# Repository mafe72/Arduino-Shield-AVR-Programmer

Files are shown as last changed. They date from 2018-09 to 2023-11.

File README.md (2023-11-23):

# Arduino Shield AVR Programmer



The Arduino software comes with an ArduinoISP sketch which allows an Arduino, correctly connected, to flash another AVR chip. With the use of other libraries like Attiny-core, this means you can use your Arduino and it’s IDE to program Attiny chips! This shield takes all the hassle out of connecting the wires, and with the simple use of a jumper cable, lets you program 8, 14, 20, and 28-pin chips with one easy-to-use zero insertion force (ZIF) socket!

- Load a bootloader on an Atmega328 as a replacement or for a breadboard project.
- Load a program on an Attiny 84, 85, or 2313 using the Arduino IDE.
- Update a program on any AVR project that has an ISP header.

License
-------
<div align="center"><br /></div>

This project is open hardware licensed under the Attribution-ShareAlike 4.0 (CC BY-SA 4.0) license. The full legal text of the license may be found in the LICENSE.md file in this repository. For more information about this license, please visit 
the Creative Commons Foundation (https://creativecommons.org/licenses/by-sa/4.0/).

Features:
-------

- Reprogram a chip in an existing circuit with an ISP header.
- Simple and easy jumper system allows programming 8, 14, 20, and 28 pin chips using a single socket.
- LEDs give the status of the programmer.
- Support for a piezo beeper for error/success audible tones.
- An indicator light on pin D3 lets you run “BLINK” on any of the chips while it is in the socket.
- Compatible with ArduinoISP, AdafruitISP, and AdaLoader.
- Tested on Duemilanove, Uno, and Mega (requires jumpers).
- Use an IDC 6 Pin Ribbon Cable to connect the ISP port to the desired IC pinout.

----------
Front Side:
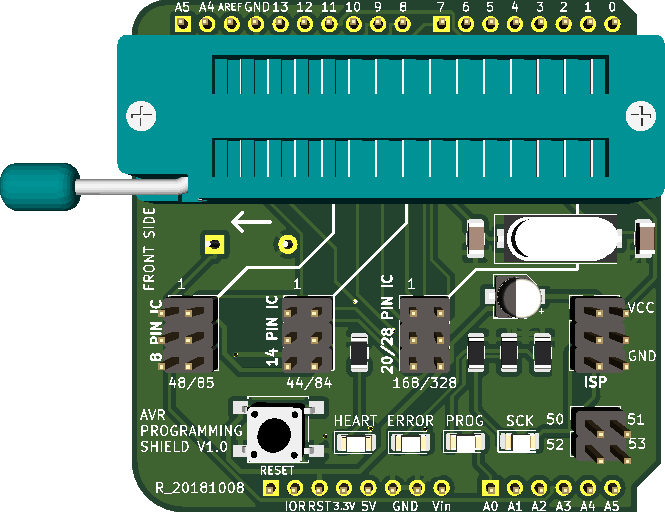
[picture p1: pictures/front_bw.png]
Arduino Shield AVR Programmer Front Side

----------
Back Side:
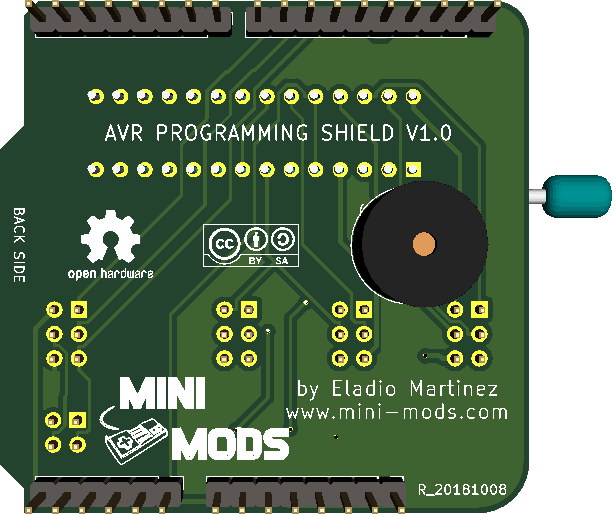
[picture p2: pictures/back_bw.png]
Arduino Shield AVR Programmer Back Side

----------

Project
-------

The PCB design was originally developed in Kicad.

# Contribution

## Suggestions and Bugs in Hardware

You should report bugs or suggestions via [Issues area](https://github.com/mafe72/Arduino-Shield-AVR-Programmer/issues) here in github.

Make sure you meet the following criteria when creating / submitting your issue:

- Use a clear and descriptive title to identify the problem / suggestion.
- Describe the exact steps to reproduce the problem in as much detail as possible.
- Mention where this problem was found / what your suggestion will affect.

## Contribution to hardware improvements

Community contributions are always welcome!

This section is intended to help anyone interested in contributing to this repository.
Before you contribute, first get approval from the repository and community maintainers by raising a problem from GitHub using the guidelines mentioned in the suggestions section.
 
Once you get approved, you will need to do the following steps (these instructions assume that you are a GitHub user).

- 1: fork this repository.
- 2: Make changes, commit and push to the fork.
- 3: Submit your Pull Request.

## If you have any questions please contact me

info@attinyuino.com

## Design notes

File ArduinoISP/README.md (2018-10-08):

Arduino Shield AVR Programmer Sketch
----------------

This sketch turns the Arduino into a AVRISP and takes advantage of the Piezo Speaker on pin A3 to provide audible tones.

If you want to program anything other than the standard bootloaders, you will need to add the appropriate "cores" to the Arduino software:

* For a "Breadboard Arduino", which is an Atmega328 running on its internal crystal at 8 MHz, you must install the files from "Breadboard.zip" at http://arduino.cc/en/Tutorial/ArduinoToBreadboard into the "hardware" folder in your Arduino "sketchbook" folder.
* For Attiny chips, there are several cores available:
	* I like [Arduino-Tiny](https://code.google.com/archive/p/arduino-tiny/) core based on work by David A. Mellis, René Bohne, R. Wiersma, Alessandro Saporetti, and Brian Cook because it supports the tone() command if you want to play sounds on a piezo speaker.
	* If you want to program the Attiny2313, you can use the [Attiny](https://github.com/damellis/attiny/) core.

Leds & buzzer:
----------------

- Green LED : HEART - (Heartbeat) shows the programmer is running.
- Red LED : ERROR - Lights up if something goes wrong and the the piezo makes a continuous beep.
- Yellow LED: PROG - (Programming) In communication with the slave, once it is done, the piezo makes a short beep.
- Blue LED: SCK  - (Activity) active when data is transmitted.

Arduino Mega:
----------------

This shield will work with the mega, but needs a 2x2 female header added in the lower right corner and four jumper wires to connect with Mega pins 50 - 53.

Settings:
----------------

1. Upload the ArduinoISP.ino provided on this section. This sketch must be uploaded without the shield in place since the shield has a capacitor to over-ride the reset signal (or you could use a manual reset before upload, like in the old-old days). Alternatively you can use the stock Arduino software "ArduinoISP" sketch included in the "Examples" section. 
2. With the sketch uploaded, install the shield. You should see the green heart LED begin it's pulsing.
3. In the IDE, select "Tools" -> "Programmer" -> "Arduino as ISP".
4. Select the target chip type using "Tools" -> "Boards".
5. Place an IDC 6 Pin (2x3) X 2 Ribbon Cable (jumper cable can also be used) between the "ISP" header and the correct header for the chip type.

Burning:
----------------

Setting fuses is a scary and confusing topic if you look in to it much. Don't bother. They are basically setting that tell the chip how to behave and have to be done only once to a new chip.

1. Place the chip in the ZIFF socket, all the way to the left, with Pin 1 in the lower-left corner.
2. With the correct "board" selected for the target chip, select "Tools" -> "Burn Bootloader".
	* For an Atmega chip going in to a UNO or breadboard, this will set the fuses and upload the correct bootloader.
	* For an Attiny, this just sets the fuses. For us, this primarily concerns chip speed. 

Upload a Sketch:
----------------

1. Load the sketch for the target chip. Start with the basic blink "File" -> "Examples" -> "01.Basics" -> "Blink".
2. Change the "led" variable from "13" to "3".
3. Click the upload icon, or "File" -> "Upload".
4. You should see the yellow LED flash and get an "Upload Complete" message.
5. If all is well, the target chip should start blinking the yellow LED (attached to D3).

Troubleshooting:
----------------

If you experience any problems double check the following:

1. "Tools" -> "Serial Port" -> Correct port selected. 
2. ArduinoISP sketch uploaded and green heartbeat beating.
	* Sometimes the sketch will hang and need a reset. 
3. "Tools" -> "Programmer" -> "Arduino as ISP".
4. "Tools" -> "Boards" -> target chip selected.
5. Jumper cable set to correct target chip type.
6. Target chip in the correct position with pin 1 to the lower left.

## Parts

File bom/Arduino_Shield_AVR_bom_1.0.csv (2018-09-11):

Component | Description | References | Value | Quantity Per PCB | MPN | Datasheet
1 | Buzzers Indicator, Internally Driven Magnetic 5V 40mA 2.3kHz 85dB @ 5V, 10cm Through Hole PC Pins | BZ1 | Buzzer | 1 | WST-1205S | http://cirlw3yrzg4afc1x47lv2k18.wpengine.netdna-cdn.com/wp-content/uploads/2016/12/WST-1205S-new.pdf
2 | 10µF 16V Aluminum Electrolytic Capacitors Radial, Can - SMD 2000 Hrs @ 85°C | C3 | 10uf | 1 | EEE-1CA100SR | https://industrial.panasonic.com/cdbs/www-data/pdf/RDE0000/ABA0000C1145.pdf
3 | 22pF ±5% 100V Ceramic Capacitor C0G, NP0 1206 (3216 Metric) | C1 C2 | 22pf | 2 | AC1206JRNPO0BN220 | http://www.yageo.com/documents/recent/UPY-AC_NP0X7R_16V-to-630V_11.pdf
4 | Red 638nm LED Indication - Discrete 1.8V 1206 (3216 Metric) | D3 | LED_ERR | 1 | LTST-C150CKT | http://optoelectronics.liteon.com/upload/download/DS-22-98-0002/LTST-C150CKT.pdf
5 | Green 569nm LED Indication - Discrete 2.1V 1206 (3216 Metric) | D4 | LED_HTE | 1 | LTST-C150GKT | http://optoelectronics.liteon.com/upload/download/DS-22-98-0004/LTST-C150GKT.pdf
6 | Yellow 591nm LED Indication - Discrete 2.1V 1206 (3216 Metric) | D2 | LED_PROG | 1 | LTST-C150KSKT | http://optoelectronics.liteon.com/upload/download/DS-22-99-0187/LTST-C150KSKT.pdf
7 | Blue 470nm LED Indication - Discrete 3.3V 1206 (3216 Metric) | D1 | LED_SCK | 1 | LTST-C150TBKT | http://optoelectronics.liteon.com/upload/download/DS22-2000-026/LTST-C150TBKT(0630).pdf
8 | CONN IC DIP SOCKET ZIF 24POS GLD | J5 | 28-PIN ZIF SOCKET | 1 | 224-5248-00-0602J | http://aitendo3.sakura.ne.jp/aitendo_data/product_img/parts/socket/LCC/3M-TEXTOOL-LCCC.PDF
9 | Connector Header Through Hole 6 position 0.100" (2.54mm) | J4 | ISP_329 | 1 | M20-9720345 | https://cdn.harwin.com/pdfs/M20-972.pdf
10 | Connector Header Through Hole 6 position 0.100" (2.54mm) | J3 | ISP_84 | 1 | M20-9720345 | https://cdn.harwin.com/pdfs/M20-972.pdf
11 | Connector Header Through Hole 6 position 0.100" (2.54mm) | J2 | ISP_85 | 1 | M20-9720345 | https://cdn.harwin.com/pdfs/M20-972.pdf
12 | Connector Header Through Hole 6 position 0.100" (2.54mm) | J1 | ISP_MASTER | 1 | M20-9720345 | https://cdn.harwin.com/pdfs/M20-972.pdf
13 | Connector Header Through Hole 4 position 0.100" (2.54mm) | J6 | MEGA_JUMPERS | 1 | 61300421121 | https://katalog.we-online.de/em/datasheet/6130xx21121.pdf
14 | Connector Header Through Hole 6 position 0.100" (2.54mm) | P2 | Analog | 1 | 61300611121 | https://katalog.we-online.de/em/datasheet/6130xx11121.pdf
15 | Connector Header Through Hole 10 position 0.100" (2.54mm) | P3 | Digital | 1 | 61301011121 | https://katalog.we-online.de/em/datasheet/6130xx11121.pdf
16 | Connector Header Through Hole 8 position 0.100" (2.54mm) | P4 | Digital | 1 | 61300811121 | https://katalog.we-online.de/em/datasheet/6130xx11121.pdf
17 | Connector Header Through Hole 8 position 0.100" (2.54mm) | P1 | Power | 1 | 61300811121 | https://katalog.we-online.de/em/datasheet/6130xx11121.pdf
18 | 330 Ohms ±1% 0.25W, 1/4W Chip Resistor 1206 (3216 Metric) Moisture Resistant Thick Film | R1 R2 R3 R4 | 330R | 4 | RC1206FR-07330RL | http://www.yageo.com/documents/recent/PYu-RC_Group_51_RoHS_L_9.pdf
19 | Tactile Switch SPST-NO Top Actuated Surface Mount | SW1 | SW_Push | 1 | TL3301AF260QG | http://spec_sheets.e-switch.com/specs/P010513.pdf
20 | 16MHz ±30ppm Crystal 18pF 30 Ohms HC-49/US | Y1 | 16MHz | 1 | 9C-16.000MAAJ-T | http://www.txccorp.com/download/products/quartz_crystals/2015TXC_9C_32.pdf

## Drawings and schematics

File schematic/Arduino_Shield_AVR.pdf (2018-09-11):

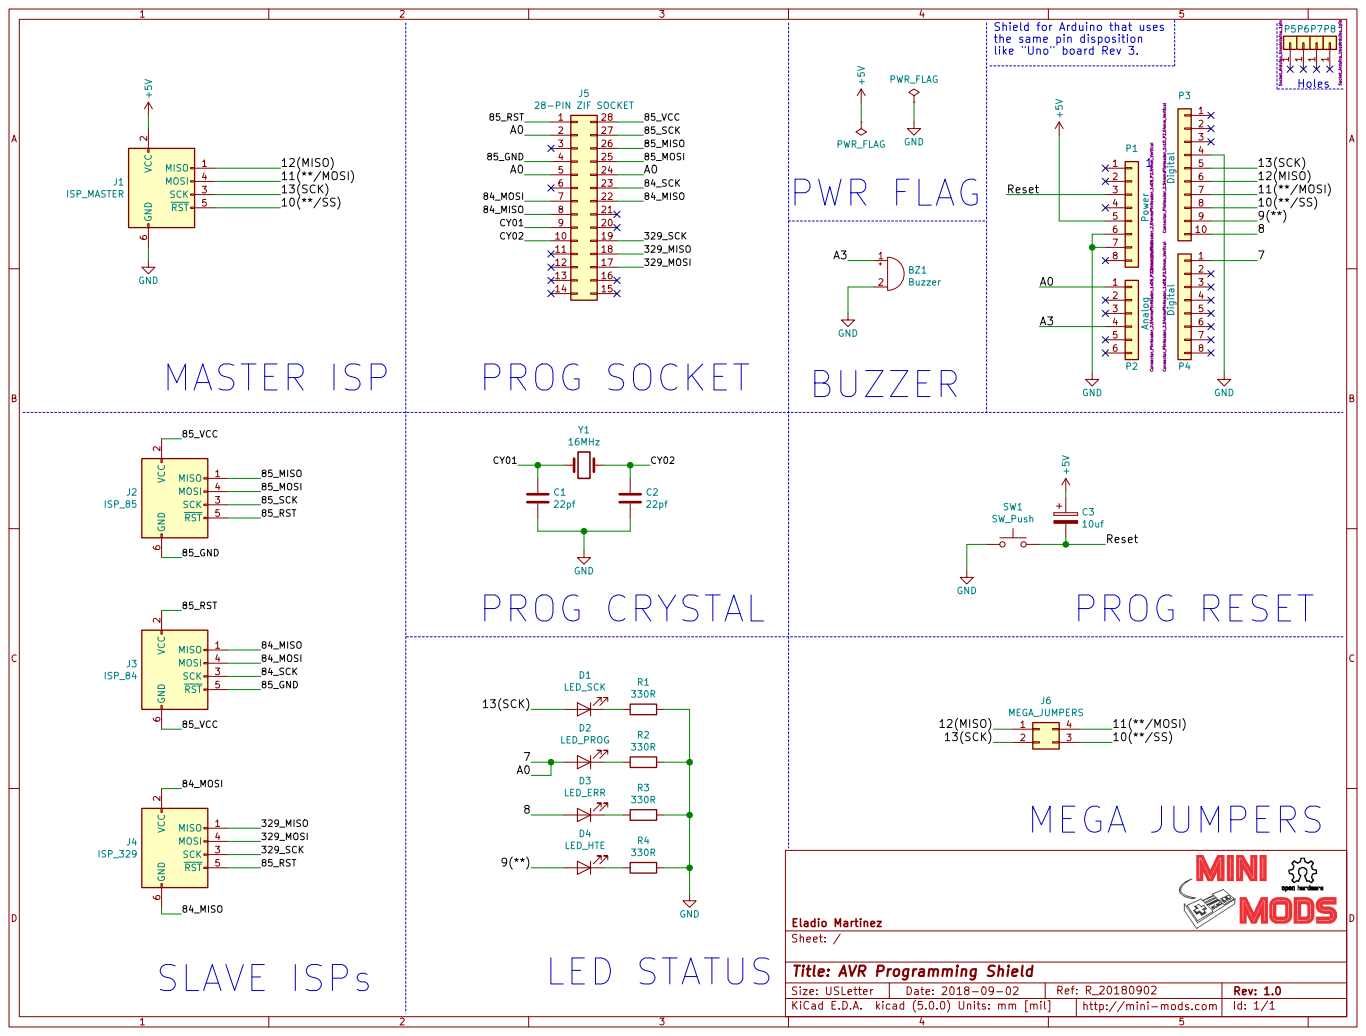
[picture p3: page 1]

13(SCK)Holes Shield for Arduino that uses
the same pin disposition
like "Uno" board Rev 3. 1

2 SCK 3 MOSI 4 RST 5 GND

Id: 1/1 Title: AVR Programming Shield

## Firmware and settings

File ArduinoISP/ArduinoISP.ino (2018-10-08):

// ArduinoISP
// Copyright (c) 2008-2011 Randall Bohn
//
// September 2018 by Eladio Martinez
// - Added support for a piezo beeper for error/success 
//
// If you require a license, see
// http://www.opensource.org/licenses/bsd-license.php
//
// This sketch turns the Arduino into a AVRISP using the following Arduino pins:
//
// Pin 10 is used to reset the target microcontroller.
//
// By default, the hardware SPI pins MISO, MOSI and SCK are used to communicate
// with the target. On all Arduinos, these pins can be found
// on the ICSP/SPI header:
//
//               MISO °. . 5V (!) Avoid this pin on Due, Zero...
//               SCK   . . MOSI
//                     . . GND
//
// On some Arduinos (Uno,...), pins MOSI, MISO and SCK are the same pins as
// digital pin 11, 12 and 13, respectively. That is why many tutorials instruct
// you to hook up the target to these pins. If you find this wiring more
// practical, have a define USE_OLD_STYLE_WIRING. This will work even when not
// using an Uno. (On an Uno this is not needed).
//
// Alternatively you can use any other digital pin by configuring
// software ('BitBanged') SPI and having appropriate defines for PIN_MOSI,
// PIN_MISO and PIN_SCK.
//
// IMPORTANT: When using an Arduino that is not 5V tolerant (Due, Zero, ...) as
// the programmer, make sure to not expose any of the programmer's pins to 5V.
// A simple way to accomplish this is to power the complete system (programmer
// and target) at 3V3.
//
// Put an LED (with resistor) on the following pins:
// 9: Heartbeat   - shows the programmer is running
// 8: Error       - Lights up if something goes wrong (use red if that makes sense)
// 7: Programming - In communication with the slave
//
// September 2018 - Eladio Martinez
// Added support for Piezo speaker
// A3: Optional - Piezo speaker
//

#include "Arduino.h"
#undef SERIAL


#define PROG_FLICKER true

// Configure SPI clock (in Hz).
// E.g. for an ATtiny @ 128 kHz: the datasheet states that both the high and low
// SPI clock pulse must be > 2 CPU cycles, so take 3 cycles i.e. divide target
// f_cpu by 6:
//     #define SPI_CLOCK            (128000/6)
//
// A clock slow enough for an ATtiny85 @ 1 MHz, is a reasonable default:

#define SPI_CLOCK 		(1000000/6)


// Select hardware or software SPI, depending on SPI clock.
// Currently only for AVR, for other architectures (Due, Zero,...), hardware SPI
// is probably too fast anyway.

#if defined(ARDUINO_ARCH_AVR)

#if SPI_CLOCK > (F_CPU / 128)
#define USE_HARDWARE_SPI
#endif

#endif

// Configure which pins to use:

// The standard pin configuration.
#ifndef ARDUINO_HOODLOADER2

#define RESET     10 // Use pin 10 to reset the target rather than SS
#define LED_HB    9
#define LED_ERR   8
#define LED_PMODE 7
#define PIEZOPIN A3

// Uncomment following line to use the old Uno style wiring
// (using pin 11, 12 and 13 instead of the SPI header) on Leonardo, Due...

// #define USE_OLD_STYLE_WIRING

#ifdef USE_OLD_STYLE_WIRING

#define PIN_MOSI	11
#define PIN_MISO	12
#define PIN_SCK		13

#endif

// HOODLOADER2 means running sketches on the ATmega16U2 serial converter chips
// on Uno or Mega boards. We must use pins that are broken out:
#else

#define RESET     	4
#define LED_HB    	7
#define LED_ERR   	6
#define LED_PMODE 	5

#endif

// By default, use hardware SPI pins:
#ifndef PIN_MOSI
#define PIN_MOSI 	MOSI
#endif

#ifndef PIN_MISO
#define PIN_MISO 	MISO
#endif

#ifndef PIN_SCK
#define PIN_SCK 	SCK
#endif

// Force bitbanged SPI if not using the hardware SPI pins:
#if (PIN_MISO != MISO) ||  (PIN_MOSI != MOSI) || (PIN_SCK != SCK)
#undef USE_HARDWARE_SPI
#endif


// Configure the serial port to use.
//
// Prefer the USB virtual serial port (aka. native USB port), if the Arduino has one:
//   - it does not autoreset (except for the magic baud rate of 1200).
//   - it is more reliable because of USB handshaking.
//
// Leonardo and similar have an USB virtual serial port: 'Serial'.
// Due and Zero have an USB virtual serial port: 'SerialUSB'.
//
// On the Due and Zero, 'Serial' can be used too, provided you disable autoreset.
// To use 'Serial': #define SERIAL Serial

#ifdef SERIAL_PORT_USBVIRTUAL
#define SERIAL SERIAL_PORT_USBVIRTUAL
#else
#define SERIAL Serial
#endif


// Configure the baud rate:

#define BAUDRATE	19200
// #define BAUDRATE	115200
// #define BAUDRATE	1000000


#define HWVER 2
#define SWMAJ 1
#define SWMIN 18

// STK Definitions
#define STK_OK      0x10
#define STK_FAILED  0x11
#define STK_UNKNOWN 0x12
#define STK_INSYNC  0x14
#define STK_NOSYNC  0x15
#define CRC_EOP     0x20 //ok it is a space...

void pulse(int pin, int times);

#ifdef USE_HARDWARE_SPI
#include "SPI.h"
#else

#define SPI_MODE0 0x00

class SPISettings {
  public:
    // clock is in Hz
    SPISettings(uint32_t clock, uint8_t bitOrder, uint8_t dataMode) : clock(clock) {
      (void) bitOrder;
      (void) dataMode;
    };

  private:
    uint32_t clock;

    friend class BitBangedSPI;
};

class BitBangedSPI {
  public:
    void begin() {
      digitalWrite(PIN_SCK, LOW);
      digitalWrite(PIN_MOSI, LOW);
      pinMode(PIN_SCK, OUTPUT);
      pinMode(PIN_MOSI, OUTPUT);
      pinMode(PIN_MISO, INPUT);
    }

    void beginTransaction(SPISettings settings) {
      pulseWidth = (500000 + settings.clock - 1) / settings.clock;
      if (pulseWidth == 0)
        pulseWidth = 1;
    }

    void end() {}

    uint8_t transfer (uint8_t b) {
      for (unsigned int i = 0; i < 8; ++i) {
        digitalWrite(PIN_MOSI, (b & 0x80) ? HIGH : LOW);
        digitalWrite(PIN_SCK, HIGH);
        delayMicroseconds(pulseWidth);
        b = (b << 1) | digitalRead(PIN_MISO);
        digitalWrite(PIN_SCK, LOW); // slow pulse
        delayMicroseconds(pulseWidth);
      }
      return b;
    }

  private:
    unsigned long pulseWidth; // in microseconds
};

static BitBangedSPI SPI;

#endif

void setup() {
  SERIAL.begin(BAUDRATE);

  pinMode(LED_PMODE, OUTPUT);
  pulse(LED_PMODE, 2);
  pinMode(LED_ERR, OUTPUT);
  pulse(LED_ERR, 2);
  pinMode(LED_HB, OUTPUT);
  pulse(LED_HB, 2);
  pinMode(PIEZOPIN, OUTPUT);
  tone(PIEZOPIN, 1700, 20);

}

int error = 0;
int pmode = 0;
// address for reading and writing, set by 'U' command
unsigned int here;
uint8_t buff[256]; // global block storage

#define beget16(addr) (*addr * 256 + *(addr+1) )
typedef struct param {
  uint8_t devicecode;
  uint8_t revision;
  uint8_t progtype;
  uint8_t parmode;
  uint8_t polling;
  uint8_t selftimed;
  uint8_t lockbytes;
  uint8_t fusebytes;
  uint8_t flashpoll;
  uint16_t eeprompoll;
  uint16_t pagesize;
  uint16_t eepromsize;
  uint32_t flashsize;
}
parameter;

parameter param;

// this provides a heartbeat on pin 9, so you can tell the software is running.
uint8_t hbval = 128;
int8_t hbdelta = 8;
void heartbeat() {
  static unsigned long last_time = 0;
  unsigned long now = millis();
  if ((now - last_time) < 40)
    return;
  last_time = now;
  if (hbval > 192) hbdelta = -hbdelta;
  if (hbval < 32) hbdelta = -hbdelta;
  hbval += hbdelta;
  analogWrite(LED_HB, hbval);
}

static bool rst_active_high;

void reset_target(bool reset) {
  digitalWrite(RESET, ((reset && rst_active_high) || (!reset && !rst_active_high)) ? HIGH : LOW);
}

void loop(void) {
  // is pmode active?
  if (pmode) {
    digitalWrite(LED_PMODE, HIGH);
    tone(PIEZOPIN, 2272, 20);
  } else {
    digitalWrite(LED_PMODE, LOW);
  }
  // is there an error?
  if (error) {
    digitalWrite(LED_ERR, HIGH);
    tone(PIEZOPIN, 1912, 20);
  } else {
    digitalWrite(LED_ERR, LOW);
  }

  // light the heartbeat LED
  heartbeat();
  if (SERIAL.available()) {
    avrisp();
  }
}

uint8_t getch() {
  while (!SERIAL.available());
  return SERIAL.read();
}
void fill(int n) {
  for (int x = 0; x < n; x++) {
    buff[x] = getch();
  }
}

#define PTIME 30
void pulse(int pin, int times) {
  do {
    digitalWrite(pin, HIGH);
    delay(PTIME);
    digitalWrite(pin, LOW);
    delay(PTIME);
  } while (times--);
}

void prog_lamp(int state) {
  if (PROG_FLICKER) {
    digitalWrite(LED_PMODE, state);
  }
}

uint8_t spi_transaction(uint8_t a, uint8_t b, uint8_t c, uint8_t d) {
  SPI.transfer(a);
  SPI.transfer(b);
  SPI.transfer(c);
  return SPI.transfer(d);
}

void empty_reply() {
  if (CRC_EOP == getch()) {
    SERIAL.print((char)STK_INSYNC);
    SERIAL.print((char)STK_OK);
  } else {
    error++;
    SERIAL.print((char)STK_NOSYNC);
  }
}

void breply(uint8_t b) {
  if (CRC_EOP == getch()) {
    SERIAL.print((char)STK_INSYNC);
    SERIAL.print((char)b);
    SERIAL.print((char)STK_OK);
  } else {
    error++;
    SERIAL.print((char)STK_NOSYNC);
  }
}

void get_version(uint8_t c) {
  switch (c) {
    case 0x80:
      breply(HWVER);
      break;
    case 0x81:
      breply(SWMAJ);
      break;
    case 0x82:
      breply(SWMIN);
      break;
    case 0x93:
      breply('S'); // serial programmer
      break;
    default:
      breply(0);
  }
}

void set_parameters() {
  // call this after reading parameter packet into buff[]
  param.devicecode = buff[0];
  param.revision   = buff[1];
  param.progtype   = buff[2];
  param.parmode    = buff[3];
  param.polling    = buff[4];
  param.selftimed  = buff[5];
  param.lockbytes  = buff[6];
  param.fusebytes  = buff[7];
  param.flashpoll  = buff[8];
  // ignore buff[9] (= buff[8])
  // following are 16 bits (big endian)
  param.eeprompoll = beget16(&buff[10]);
  param.pagesize   = beget16(&buff[12]);
  param.eepromsize = beget16(&buff[14]);

  // 32 bits flashsize (big endian)
  param.flashsize = buff[16] * 0x01000000
                    + buff[17] * 0x00010000
                    + buff[18] * 0x00000100
                    + buff[19];

  // AVR devices have active low reset, AT89Sx are active high
  rst_active_high = (param.devicecode >= 0xe0);
}

void start_pmode() {

  // Reset target before driving PIN_SCK or PIN_MOSI

  // SPI.begin() will configure SS as output, so SPI master mode is selected.
  // We have defined RESET as pin 10, which for many Arduinos is not the SS pin.
  // So we have to configure RESET as output here,
  // (reset_target() first sets the correct level)
  reset_target(true);
  pinMode(RESET, OUTPUT);
  SPI.begin();
  SPI.beginTransaction(SPISettings(SPI_CLOCK, MSBFIRST, SPI_MODE0));

  // See AVR datasheets, chapter "SERIAL_PRG Programming Algorithm":

  // Pulse RESET after PIN_SCK is low:
  digitalWrite(PIN_SCK, LOW);
  delay(20); // discharge PIN_SCK, value arbitrarily chosen
  reset_target(false);
  // Pulse must be minimum 2 target CPU clock cycles so 100 usec is ok for CPU
  // speeds above 20 KHz
  delayMicroseconds(100);
  reset_target(true);

  // Send the enable programming command:
  delay(50); // datasheet: must be > 20 msec
  spi_transaction(0xAC, 0x53, 0x00, 0x00);
  pmode = 1;
}

void end_pmode() {
  SPI.end();
  // We're about to take the target out of reset so configure SPI pins as input
  pinMode(PIN_MOSI, INPUT);
  pinMode(PIN_SCK, INPUT);
  reset_target(false);
  pinMode(RESET, INPUT);
  pmode = 0;
}

void universal() {
  uint8_t ch;

  fill(4);
  ch = spi_transaction(buff[0], buff[1], buff[2], buff[3]);
  breply(ch);
}

void flash(uint8_t hilo, unsigned int addr, uint8_t data) {
  spi_transaction(0x40 + 8 * hilo,
                  addr >> 8 & 0xFF,
                  addr & 0xFF,
                  data);
}
void commit(unsigned int addr) {
  if (PROG_FLICKER) {
    prog_lamp(LOW);
  }
  spi_transaction(0x4C, (addr >> 8) & 0xFF, addr & 0xFF, 0);
  if (PROG_FLICKER) {
    delay(PTIME);
    prog_lamp(HIGH);
  }
}

unsigned int current_page() {
  if (param.pagesize == 32) {
    return here & 0xFFFFFFF0;
  }
  if (param.pagesize == 64) {
    return here & 0xFFFFFFE0;
  }
  if (param.pagesize == 128) {
    return here & 0xFFFFFFC0;
  }
  if (param.pagesize == 256) {
    return here & 0xFFFFFF80;
  }
  return here;
}


void write_flash(int length) {
  fill(length);
  if (CRC_EOP == getch()) {
    SERIAL.print((char) STK_INSYNC);
    SERIAL.print((char) write_flash_pages(length));
  } else {
    error++;
    SERIAL.print((char) STK_NOSYNC);
  }
}

uint8_t write_flash_pages(int length) {
  int x = 0;
  unsigned int page = current_page();
  while (x < length) {
    if (page != current_page()) {
      commit(page);
      page = current_page();
    }
    flash(LOW, here, buff[x++]);
    flash(HIGH, here, buff[x++]);
    here++;
  }

  commit(page);

  return STK_OK;
}

#define EECHUNK (32)
uint8_t write_eeprom(unsigned int length) {
  // here is a word address, get the byte address
  unsigned int start = here * 2;
  unsigned int remaining = length;
  if (length > param.eepromsize) {
    error++;
    return STK_FAILED;
  }
  while (remaining > EECHUNK) {
    write_eeprom_chunk(start, EECHUNK);
    start += EECHUNK;
    remaining -= EECHUNK;
  }
  write_eeprom_chunk(start, remaining);
  return STK_OK;
}
// write (length) bytes, (start) is a byte address
uint8_t write_eeprom_chunk(unsigned int start, unsigned int length) {
  // this writes byte-by-byte, page writing may be faster (4 bytes at a time)
  fill(length);
  prog_lamp(LOW);
  for (unsigned int x = 0; x < length; x++) {
    unsigned int addr = start + x;
    spi_transaction(0xC0, (addr >> 8) & 0xFF, addr & 0xFF, buff[x]);
    delay(45);
  }
  prog_lamp(HIGH);
  return STK_OK;
}

void program_page() {
  char result = (char) STK_FAILED;
  unsigned int length = 256 * getch();
  length += getch();
  char memtype = getch();
  // flash memory @here, (length) bytes
  if (memtype == 'F') {
    write_flash(length);
    return;
  }
  if (memtype == 'E') {
    result = (char)write_eeprom(length);
    if (CRC_EOP == getch()) {
      SERIAL.print((char) STK_INSYNC);
      SERIAL.print(result);
    } else {
      error++;
      SERIAL.print((char) STK_NOSYNC);
    }
    return;
  }
  SERIAL.print((char)STK_FAILED);
  return;
}

uint8_t flash_read(uint8_t hilo, unsigned int addr) {
  return spi_transaction(0x20 + hilo * 8,
                         (addr >> 8) & 0xFF,
                         addr & 0xFF,
                         0);
}

char flash_read_page(int length) {
  for (int x = 0; x < length; x += 2) {
    uint8_t low = flash_read(LOW, here);
    SERIAL.print((char) low);
    uint8_t high = flash_read(HIGH, here);
    SERIAL.print((char) high);
    here++;
  }
  return STK_OK;
}

char eeprom_read_page(int length) {
  // here again we have a word address
  int start = here * 2;
  for (int x = 0; x < length; x++) {
    int addr = start + x;
    uint8_t ee = spi_transaction(0xA0, (addr >> 8) & 0xFF, addr & 0xFF, 0xFF);
    SERIAL.print((char) ee);
  }
  return STK_OK;
}

void read_page() {
  char result = (char)STK_FAILED;
  int length = 256 * getch();
  length += getch();
  char memtype = getch();
  if (CRC_EOP != getch()) {
    error++;
    SERIAL.print((char) STK_NOSYNC);
    return;
  }
  SERIAL.print((char) STK_INSYNC);
  if (memtype == 'F') result = flash_read_page(length);
  if (memtype == 'E') result = eeprom_read_page(length);
  SERIAL.print(result);
}

void read_signature() {
  if (CRC_EOP != getch()) {
    error++;
    SERIAL.print((char) STK_NOSYNC);
    return;
  }
  SERIAL.print((char) STK_INSYNC);
  uint8_t high = spi_transaction(0x30, 0x00, 0x00, 0x00);
  SERIAL.print((char) high);
  uint8_t middle = spi_transaction(0x30, 0x00, 0x01, 0x00);
  SERIAL.print((char) middle);
  uint8_t low = spi_transaction(0x30, 0x00, 0x02, 0x00);
  SERIAL.print((char) low);
  SERIAL.print((char) STK_OK);
}
//////////////////////////////////////////
//////////////////////////////////////////


////////////////////////////////////
////////////////////////////////////
void avrisp() {
  uint8_t ch = getch();
  switch (ch) {
    case '0': // signon
      error = 0;
      empty_reply();
      break;
    case '1':
      if (getch() == CRC_EOP) {
        SERIAL.print((char) STK_INSYNC);
        SERIAL.print("AVR ISP");
        SERIAL.print((char) STK_OK);
      }
      else {
        error++;
        SERIAL.print((char) STK_NOSYNC);
      }
      break;
    case 'A':
      get_version(getch());
      break;
    case 'B':
      fill(20);
      set_parameters();
      empty_reply();
      break;
    case 'E': // extended parameters - ignore for now
      fill(5);
      empty_reply();
      break;
    case 'P':
      if (!pmode)
        start_pmode();
      empty_reply();
      break;
    case 'U': // set address (word)
      here = getch();
      here += 256 * getch();
      empty_reply();
      break;

    case 0x60: //STK_PROG_FLASH
      getch(); // low addr
      getch(); // high addr
      empty_reply();
      break;
    case 0x61: //STK_PROG_DATA
      getch(); // data
      empty_reply();
      break;

    case 0x64: //STK_PROG_PAGE
      program_page();
      break;

    case 0x74: //STK_READ_PAGE 't'
      read_page();
      break;

    case 'V': //0x56
      universal();
      break;
    case 'Q': //0x51
      error = 0;
      end_pmode();
      empty_reply();
      break;

    case 0x75: //STK_READ_SIGN 'u'
      read_signature();
      break;

    // expecting a command, not CRC_EOP
    // this is how we can get back in sync
    case CRC_EOP:
      error++;
      SERIAL.print((char) STK_NOSYNC);
      break;

    // anything else we will return STK_UNKNOWN
    default:
      error++;
      if (CRC_EOP == getch())
        SERIAL.print((char)STK_UNKNOWN);
      else
        SERIAL.print((char)STK_NOSYNC);
  }
}
